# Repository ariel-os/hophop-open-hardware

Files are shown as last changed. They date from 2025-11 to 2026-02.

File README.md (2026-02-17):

hophop: Open Hardware
=====================

This repository will eventually contain the design files
for hardware developed for hophop as inside the Ariel OS project.

Items
-----

* [HopHop Devkit 1](./design-decisions/hophop-devkit-1.md)

  Status: Currently, this is a sketch, while precise requirements are drafted.

Branding
--------

These boards are developed as part of the Ariel OS project (as is the hophop stack),
will run Ariel OS based software from the start,
and come with the Ariel OS logo.

License
-------

Data in this repository is licensed under the terms of [CERN-OHL-P-2.0](https://ohwr.org/cern_ohl_p_v2.pdf).

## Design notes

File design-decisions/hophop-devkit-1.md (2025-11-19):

Purpose
=======

The development board should facilitate the development of open mobile communication applications
based on DECT-2020 NR+.

It should allow users to try out hophop,
explore audio and IP applications on it,
and gather experience with mobile use based on battery or other power sources.

Components
==========

Note that this is an early design sketch:
Most components are up for discussion if they prove to be overly complicated or costly;
alternative suggestions are always welcome.

Can we fit this in about 7x13cm?

Main cores
----------

* nRF9151, with DECT radio core firmware flashed on before shipping
  * Antenna, 4x antenna selector GPIO routed to Antenna domain
  * I2C participation in Board Control Bus
  * SPI master and UART with HW flow control to nRF54

    UART may not technically be necessary because we can frame SPI as we like,
    but it can be convenient for some development scenarios.

  * I2S bi-directional (plus PDM any GPIO we need there) routed to audio domain with off-by-default solder jumpers.

  * Co-exist pin to nRF54
  * SWD 10-pin header and 6-pin Tag-Connect

  * Any pins needed for the Peripherals group.

* nRF54H20 (or nRF54LM20A, if H20 is not available?)
  * SPI slave and UART to 9151
  * I2C participation in Board Control Bus
  * Co-exist from nRF9151
  * The full set of USB connectivity, including PD (but see also Power domain)
  * SWD 10-pin header and 6-pin Tag-Connect

  * I2S bi-directional (plus PDM any GPIO we need there) routed to audio domain with on-by-default solder jumpers.

  * 2.4GHz chip antenna

  * Any pins needed for the Peripherals group.

* Mutual RST connections.

Antenna domain
--------------

* Direct line to 1.9GHz chip antenna,
  broken only by on-by-default solder jumpers.
* Solder jumpers allow diverting the signal into a pair of connectors (eg. MMCX) instead.

  When switched to this configuration,
  it provides several options to be explored later:

  * A dummy load between the two connectors can be inserted into the transmit path to emulate obstacles when doing testing between nodes in physical proximity.
  * The signal from the chip can be fed into a spectrum analyzer;
    in this configuration, the channel back into the antenna is unused.
  * Antenna diversity can be explored:
    The 2nd board can contain more directional antennas
    or antennas for different bands,
    with an antenna selector (up to 4 channels) feeding into those and/or back into the main antenna.

* Screw terminals that allow any of the above to be put in place on the board,
  rather than setting up flimsy wires.

* 4 GPIOs and the I2C Board Control Bus (plus GND/VCC) for antenna selection and metadata.

  These could be connected by an 8-pin IDC block, or anything that works both for screw-on daughter boards
  and for wiring up the external antenna components separately.

  The purpose of the I2C is to allow having a cheap simple I2C storage component on the radio boards,
  which then tell the radio MCU which antenna selection options are available,
  and which antennas are connected.

Ideally, I'd like to sense on the radio MCU whether or not the solder bridges are configured this or that way,
so that a situation of the bridges set to external connection but no external board being present can be detected.
Without some genius idea,
this could just as well be one more set of solder bridges taking a GPIO to GND or VCC,
with strict instructions to only change all three solder bridges or risk damage to the radio.

Peripherals
-----------

* Break-out of the nRF91 SPI bus (on a dedicated CS) and UART with HW flow control (ideally separate, otherwise shared with protection against nRF54 and external sending at the same time) to Board Control Bus at 3.3V level.

  Which connectors do we best pick to go into a SPI and UART capable PC style / Linux system such as a RasPi?
  Maybe Molex KK 254?
  
* Break-out connectors.

  If we have pins to spare, solder-jumpered between nRF91 and nRF54 (defaulting to the latter),
  otherwise only nRF54.
  Assigning to different pins is preferred, but if they share an SPI or I2C bus, that's OK too.

  * 2x Grove
  * 1x UEXT (don't share I2C, those are often also used as GPIO)
  * 1x mikroBUS (especially the analog pin is really best-effort)

  * Maybe Arduino UNO headers
    (Or what are your favorite form factors?)

* "The usual buttons and LEDs":
  all connected to the nRF54,
  optionally (LEDs via solder jumpers) to the nRF54 core
  (TBD: Really the nRF54? Those might make sense on the nRF91 as well, because they make sense even when connected to a PC; not sure what's best here.)

  * 4 user LEDs
  * 4 user buttons

    TBD: front? edge? 2 front, 2 edge?

  * Boot mode button (or buttons? TBD; Need to look into bootloader plans)

Audio domain
------------

* DAC from I2S, output strong enough to drive headphones.

  TBD: Stereo? Probably that's in all chips anyway.

* ADC into I2S, suitable for headsets.

  TBD: Do we need to do any gain control?

* PDM on-board MEMS microphone (something in the ballpark of MP34DB02)

  Data and VCC wired through on-by-default solder jumper
  (doesn't need to be R0, suffices to have easy place to cut)
  so users who run firmware they do not trust can disable it.

* 3.5mm TRRS connector, with insertion detection

  TBD: Those have different pinouts used in different environments (CTIA vs. OMTP);
  can we cater for both, if so, how do we route it,
  and can we auto-detect it?

  TBD: Should we have another TRS to have split mic/phone headsets, are they still a thing?

TBD: There are headsets with PTT; how is that signalled?

Power domain
------------

* Connector to Li(Fe?)Po battery

* Power inputs
  (not sure if best going into main power domain, or if fed into charge controller;
  if the latter, can this still run without a battery connected?)

  * 6-48V DC input ("works with any power adapter you may have lying around"). Screw terminal?

  * MPP tracker to connect solar modules.

* Charge controller 

  * Managing battery

  * Providing VCC to nRF54 and nRF91

  * Sending and receiving power via USB-C. Up to … TBD, maybe 500mA?

  TBD:
  Are charge controllers that do bi-directional USB generally taking the PD lines?
  (In which case: can we get some information about SoC, and control, back into the nRF54?)
  Or do they need an MCU to talk PD and tell the charge controller?
  The former would be preferred.

Other features
--------------

Many test points don't hurt.

The purpose of the Board Control Bus is that no matter how an application uses the board
(e.g. from USB, from the direct-to-PC SPI-UART-I2C connector, or in standalone mode driven by either controller),
application developers can reach all involved components.

This is an evaluation and testing tool.
Other similar boards have labels such as "For evaluation only; not FCC approved for resale".

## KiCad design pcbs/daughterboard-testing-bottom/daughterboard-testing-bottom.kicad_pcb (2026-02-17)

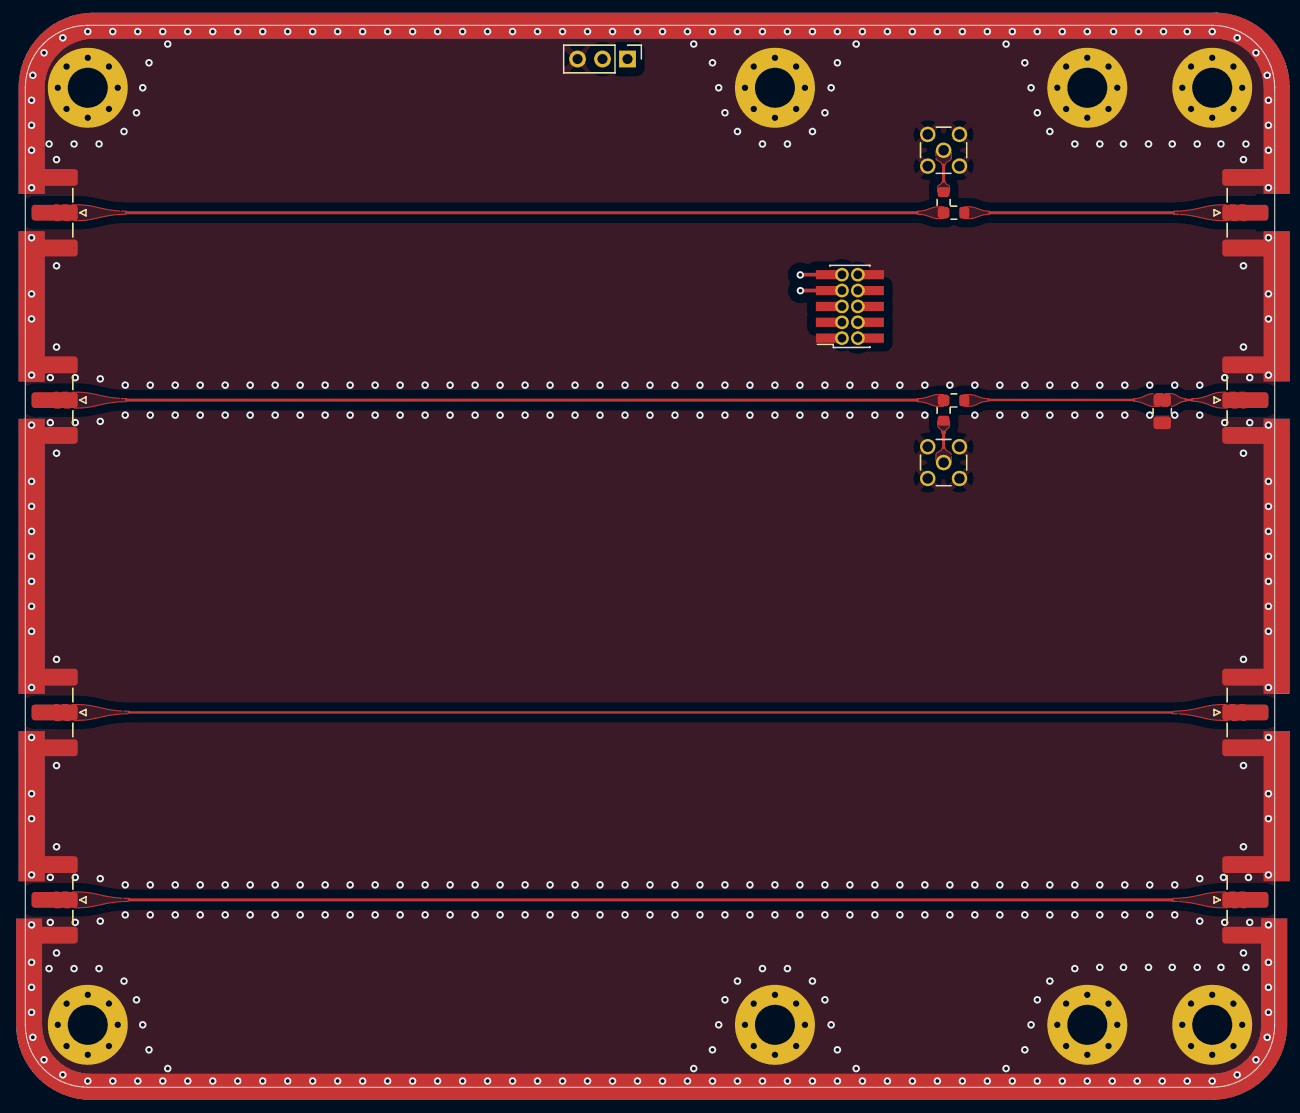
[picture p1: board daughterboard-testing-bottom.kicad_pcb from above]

Board: 4 copper layers, 100.0 x 85.0 mm, 25 parts (0 on the bottom side), 11 nets.

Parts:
H1, H2, H3, H4, H5, H6, H7, H8: MH_P; MountingHole_3.2mm_M3_Pad_Via
J1, J2: MMCX-J-P-H-ST-TH1; MMCX_Samtec_MMCX-J-P-H-ST-TH1_Vertical
J3, J4, J5, J6, J7, J8, J9, J10: CON-SMA-EDGE-S; SMA_RF_Solutions_CON-SMA-EDGE-S_EdgeMount
J11: 10165448-00010C1LF; PinSocket_2x05_P1.27mm_Vertical_SMD_Holes
J12: 22-27-2031; PinHeader_1x03_P2.00mm_Vertical
R1, R2, R3, R4: 0; R_0603_1608Metric
R5: 50; R_0805_2012Metric

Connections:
/D+: J11.9, J12.1
/D-: J11.7, J12.2
GND: H1.1, H2.1, H3.1, H4.1, H5.1, H6.1, H7.1, H8.1, J1.2 (Ext), J2.2 (Ext), J3.2 (Ext), J4.2 (Ext), J5.2 (Ext), J6.2 (Ext), J7.2 (Ext), J8.2 (Ext), J9.2 (Ext), J10.2 (Ext), J11.1, J11.10, J12.3, R5.2
unnamed: J1.1 (In), R2.1
unnamed: J2.1 (In), R3.1
unnamed: J3.1 (In), R1.1, R2.2
unnamed: J4.1 (In), R3.2, R4.1
unnamed: J5.1 (In), R1.2
unnamed: J6.1 (In), R4.2, R5.1
unnamed: J7.1 (In), J9.1 (In)
unnamed: J8.1 (In), J10.1 (In)

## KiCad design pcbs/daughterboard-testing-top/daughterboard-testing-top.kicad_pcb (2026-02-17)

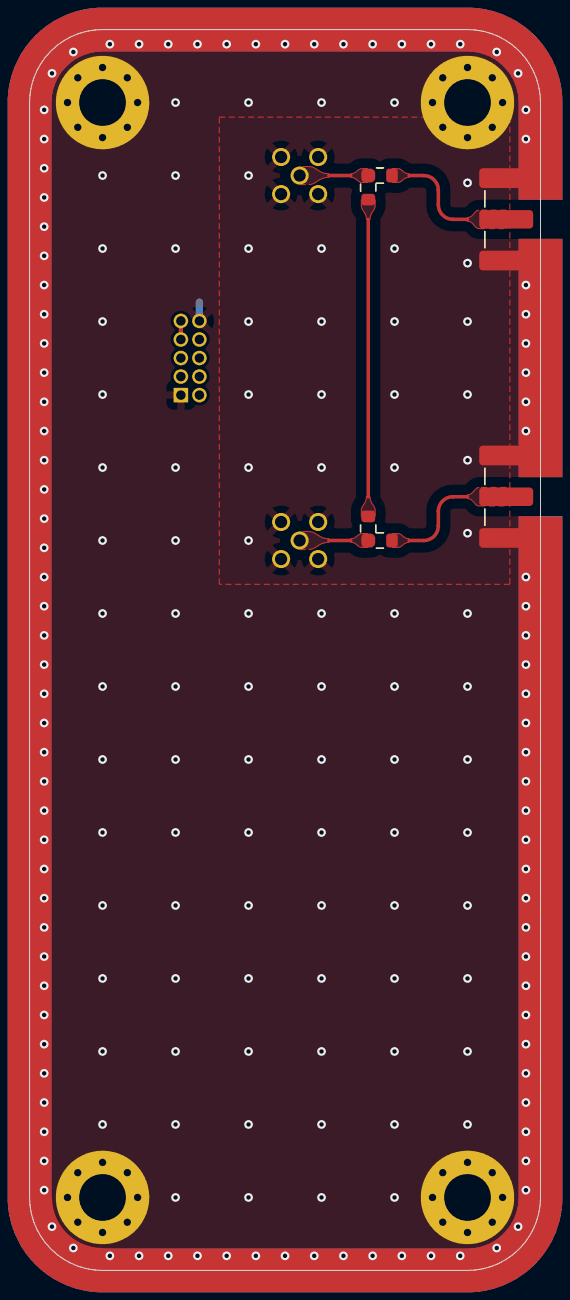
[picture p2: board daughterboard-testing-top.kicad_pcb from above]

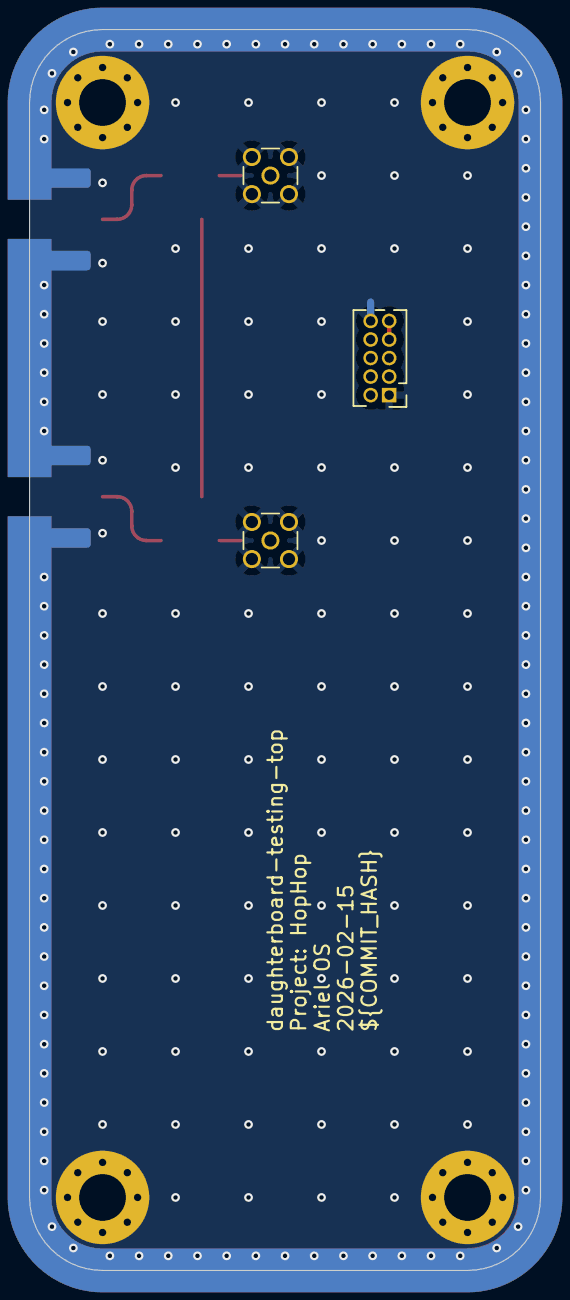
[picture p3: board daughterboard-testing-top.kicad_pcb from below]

Board: 4 copper layers, 35.0 x 85.0 mm, 13 parts (3 on the bottom side), 7 nets.

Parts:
H1, H2, H3, H4: MH_P; MountingHole_3.2mm_M3_Pad_Via
J1, J2: CON-SMA-EDGE-S; SMA_RF_Solutions_CON-SMA-EDGE-S_EdgeMount
J3, J4: MMCX-P-P-H-ST-TH1; MMCX_Samtec_MMCX-P-P-H-ST-TH1_Vertical
J5: Conn_02x05_Odd_Even; PinHeader_2x05_P1.27mm_Vertical
R1, R2, R3, R4: 0; R_0603_1608Metric

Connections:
GND: H1.1, H2.1, H3.1, H4.1, J1.2 (Ext), J2.2 (Ext), J3.2 (Ext), J4.2 (Ext), J5.1, J5.10
unnamed: J1.1 (In), R1.2
unnamed: J2.1 (In), R4.1
unnamed: J3.1 (In), R1.1, R2.2
unnamed: J4.1 (In), R3.2, R4.2
unnamed: J5.7, J5.9
unnamed: R2.1, R3.1

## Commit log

2025-11-14 Use consistent Board Control Bus
2025-11-14 Concrete connector and interface suggestions
2025-11-25 Setup pcb schematic and board file
    [hophop-devkit-1.kicad_pcb, hophop-devkit-1.kicad_sch]
2026-02-16 Add daughterboard testing pcbs (top and bottom)
    [daughterboard-testing-bottom.kicad_pcb, daughterboard-testing-bottom.kicad_sch, daughterboard-testing-top.kicad_pcb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]
2026-02-16 replace project name text variable
    ...with hardcoded text, as some manufacturers require upload of
    project-agnostic .kicad_pcb file
    [daughterboard-testing-bottom.kicad_pcb, daughterboard-testing-top.kicad_pcb]
2026-02-17 factor out devkit-rev-010
    [hophop-devkit-1.kicad_pcb, hophop-devkit-1.kicad_sch]
2026-05-01 Rename PowerModule
2026-11-09 Committing changes and new boards from team scratchpad
2026-11-09 chore: remove .kicad_prl file
2026-11-09 schematic: change drawing size to A3
2026-11-09 cleanup: top-level schematic
2026-11-09 initial schematic version
2026-11-09 Fix global labels. Remove old import power symbols
2026-11-09 Fix VDD_GPIO connected to GND
2026-11-09 cleanup: finish schematic
2026-11-09 layout: initial footprint placement
2026-11-09 layout: add 3D models and refine footprint placement
2026-11-09 layout: route six-layer board and set fabrication rules
2026-11-09 schematic: minor error fixes
2026-11-09 replace ESD diodes and RGB led with more suitable parts
2026-11-09 dfm: adjust TPS63901 pad spacing to 0.1 mm (matching datasheet), to allow more PCB manufacturers
2026-11-09 add correct silkscreen and improve RF routing
2026-11-09 Add case and tools used to generate it
2026-11-09 add missing 3d models for two diodes
2026-11-09 Case: Add missing hole
2026-11-09 use Murata Inductor for Buck converter
2026-11-09 Case: Add README
2026-11-09 Rename files after merging histories, aligning with working title of boards
